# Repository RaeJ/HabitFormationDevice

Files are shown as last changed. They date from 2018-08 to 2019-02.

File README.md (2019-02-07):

# Multisensory Book

This is an IOT device that can be controlled using Alexa. Routines can be set up using the Alexa app so that at the designated
time the book will open up and use a variety of modalities to get the users' attention. The code used to make the sound work is 
from [SFX-I2S-web-trigger](https://github.com/bbx10/SFX-I2S-web-trigger) whilst the code used for being able to connect to
Alexa is from [arduino-esp8266-alexa-wemo-switch](https://github.com/kakopappa/arduino-esp8266-alexa-wemo-switch).

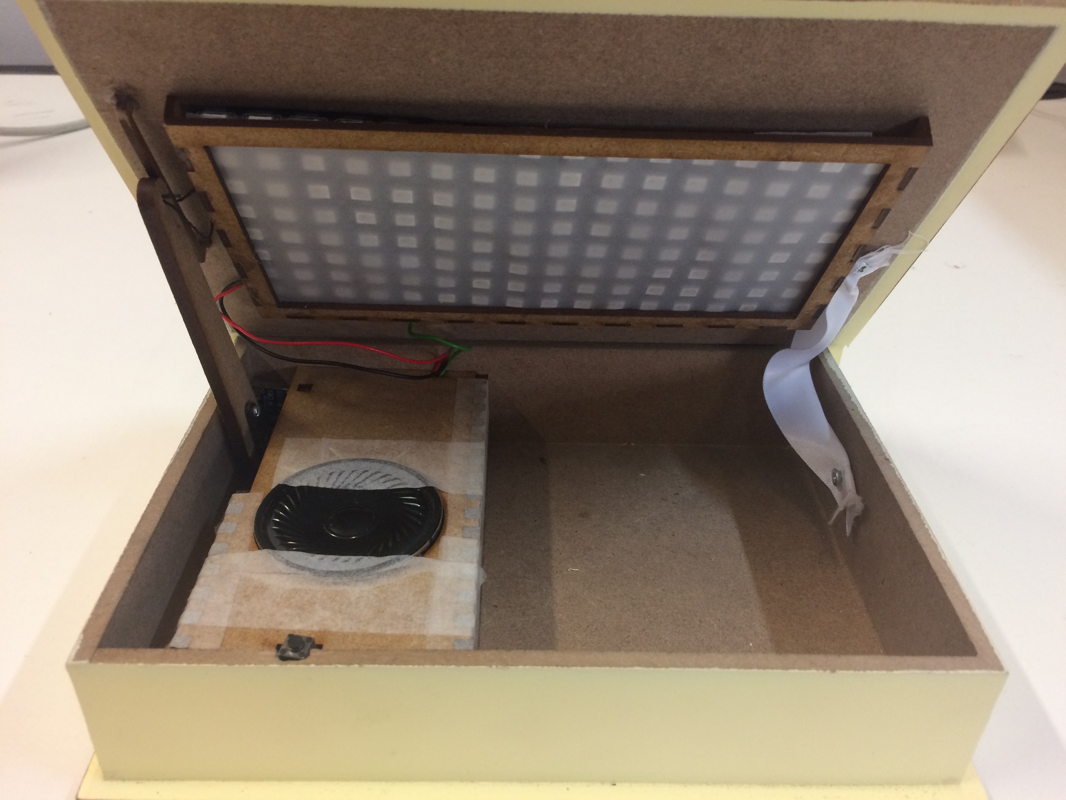
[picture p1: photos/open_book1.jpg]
Multisensory Book


## How to run the device
### Initial Code Setup
1. Download the repository. Some of the files relate to how to make the physical device. The files you need to make sure you have for the code are "book_device.ino", "wavspiffs.cpp", "wavspiffs.h" and "data". "data" contains the .wav file that the device plays and the "wavspiffs" files are from [bbx10](https://github.com/bbx10/SFX-I2S-web-trigger). The main file we are concerned with is "book_device.ino".
2. Change the network name and password. These can be found as follows in the code. If using eduroam take a look at the section of the readme on **Internet Access**.
```
const char* ssid = "NameOfNetwork";  // CHANGE: Wifi name
const char* password = "AardvarkBadgerHedgehog";  // CHANGE: Wifi password 
String friendlyName = "TheDevice";        // CHANGE: Alexa device name
```
You can also change the name of the device should you so wish.

### Initial Arduino Editor Setup
Based off the [Arduino IDE for ESP8266](https://learn.adafruit.com/adafruit-feather-huzzah-esp8266/using-arduino-ide) and the [file system setup](http://esp8266.github.io/Arduino/versions/2.0.0/doc/filesystem.html).

1. Install the the [SiLabs CP2104 Driver](https://www.silabs.com/products/development-tools/software/usb-to-uart-bridge-vcp-drivers). This will allow you to upload code to the ESP8266 using a micro USB cable to the Feather HUZZAH with the other side in your computer's USB port.
2. Install the [Arduino IDE 1.6.8 or greater](https://www.arduino.cc/en/Main/Software) and open it up.
3. Install the ESP8266 Board Package. To do this navigate to *Arduino* *Preferences* and enter `http://arduino.esp8266.com/stable/package_esp8266com_index.json` into the *Additional Board Manager URLs* field. Then navigate to the *Boards Manager* (found under *Tools*->*Board*) and install the ESP8266 Board Package. Close the Boards Manager window once the install process has completed. [This guide](https://learn.adafruit.com/add-boards-arduino-v164) is a good resource to use if you have trouble adding 3rd party boards.
4. Restart the Arduino Editor.
5. Select Adafruit Feather HUZZAH ESP8266  from the *Tools*->*Board* dropdown. Whilst still in *Tools* set the *CPU frequency* as 80MHz. The *Flash Size* can be kept at 4M (3M SPIFFS). For *Upload Speed*, select 115200 baud. You will also need to set the port as whichever port you are using.

From here we want to install the ESP8266FS tool.
1. Download the tool: https://github.com/esp8266/arduino-esp8266fs-plugin/releases/download/0.1.3/ESP8266FS-0.1.3.zip.
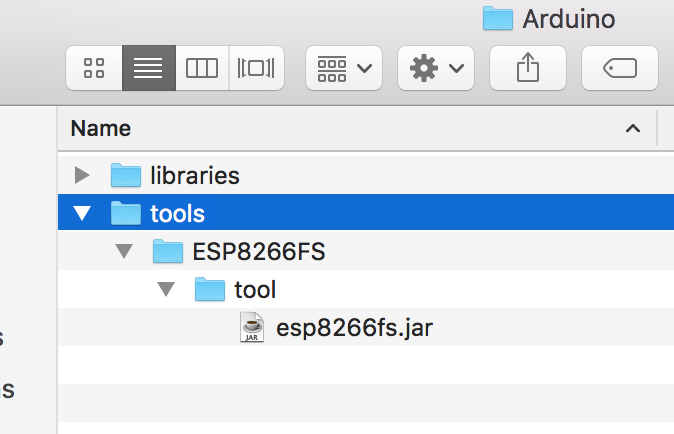
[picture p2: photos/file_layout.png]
File layout
2. In your Arduino sketchbook directory, create tools directory if it doesn't exist yet. Unpack the tool into tools directory, the path should look like `<home_dir>/Arduino/tools/ESP8266FS/tool/esp8266fs.jar`.
3. Restart the Arduino Editor. Under *Tools* there should now be an option for *ESP8266 Sketch Data Upload*.

### Uploading the code to the Feather HUZZAH
1. Connect any data-capable micro USB cable to the Feather HUZZAH and the other side to your computer's USB port. This can be done by carefully pushing the Feather HUZZAH down so it slightly sticks out of the bottom of its encasing box (as shown in the photo). 
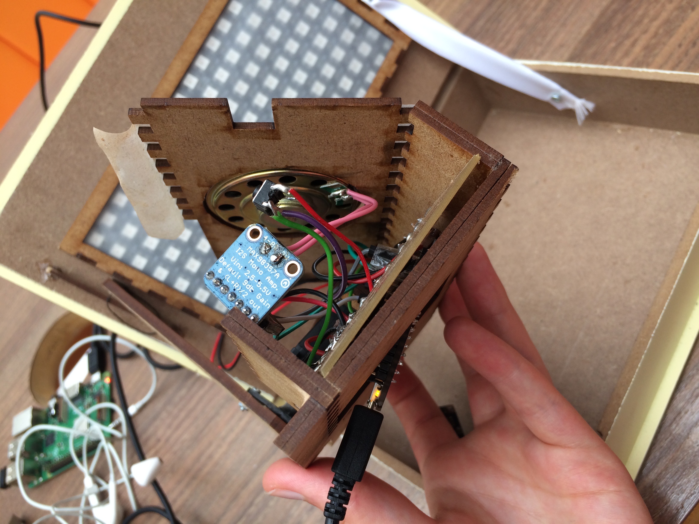
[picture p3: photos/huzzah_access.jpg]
Accessing the Feather HUZZAH


2. Make sure that the Arduino Editor is set to the correct port (*Tools*->*Port*).
3. If you have changed the .wav file in "data", or it is your first time uploading the file to the Feather Huzzah, click on *ESP8266 Sketch Data Upload* in *Tools* and wait for it to upload.
4. When that is finished click the upload button in the Arduino Editor to upload the code to the Feather Huzzah.

### Modality Switching
If you wish to change the intensity of the device this can be done simply by altering this piece of code:
```
// Mode of intensity
char subtle = 'S';
char mediocre = 'M';
char intensive = 'I';

char mode = subtle;
```
Simply change `char mode =` depending on what you want. Then re-upload the code to the Feather HUZZAH

### Controlling the device with Alexa
1. Set up your Alexa device with the Alexa App.
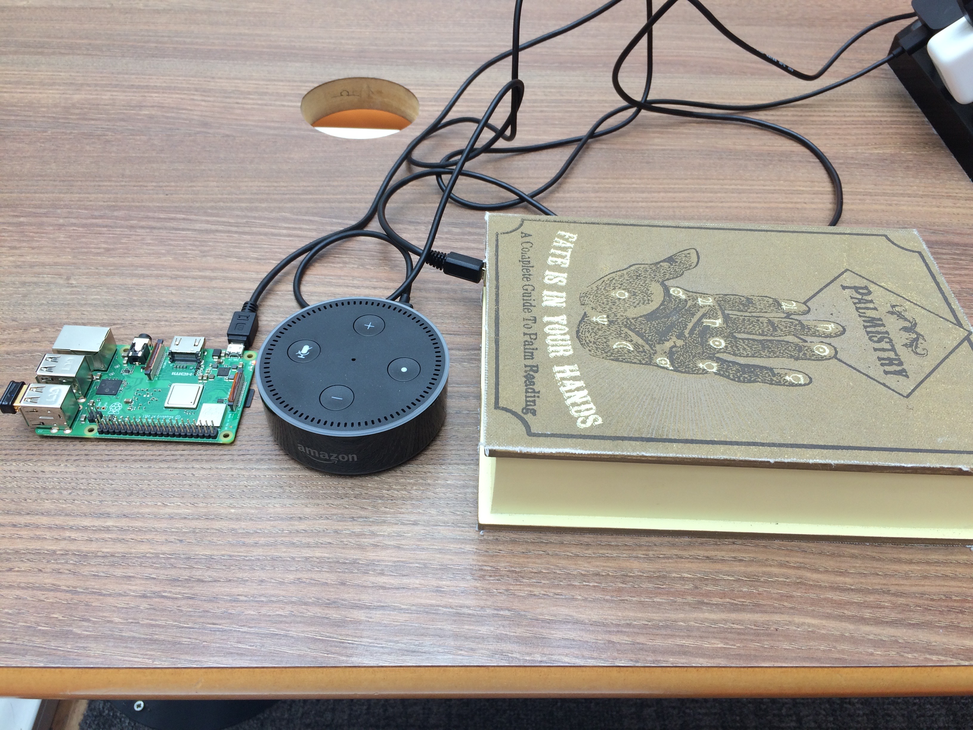
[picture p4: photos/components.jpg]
Components set up
2. Make sure that you are connected to the internet and the device is powered on. 
3. Go into *Settings*->*Smart Home* and click *Add Device*. Alexa should discover the device under the friendly name you've chosen for it.
4. From here you can treat the device as you would any other smart home device, you can create routines for it and turn it on and off with Alexa via voice command.

## Internet Access
The Raspberry Pi is simply used for internet access. In order for the device to be able to work both the ESP8266 and the Alexa need internet access. If you're using a secure network (such as eduroam) it may be difficult to connect up the devices. I'm using a Raspberry Pi 3 B+ and a USB wifi dongle. I connect the wifi dongle up to eduroam by following [these instructions](https://www.willprice.org/2014/03/17/eduroam-on-the-raspberry-pi.html) by the wonderful Will Price, simply replacing wlan0 with wlan1. I then set the wifi chip on the Raspberry Pi board up as a hotspot by following [this guide](https://www.raspberrypi.org/documentation/configuration/wireless/access-point.md). From here you can connect to the hotspot which should then give you access to eduroam and the internet.

When setting up eduroam on the Raspberry Pi I initially made the mistake of running the wpa_supplicant more than once. If you type `pgrep wpa_supplicant` into your terminal there should be only one process running. If there is more then one you can type `pkill wpa_supplicant` to kill them and start over.

Further to this, following Will Price's instructions did give me internet access, however, I initially had to repeat the process every time I restarted the Raspberry Pi. The easy fix for this was to move the terminal commands into the /etc/rc.local file.

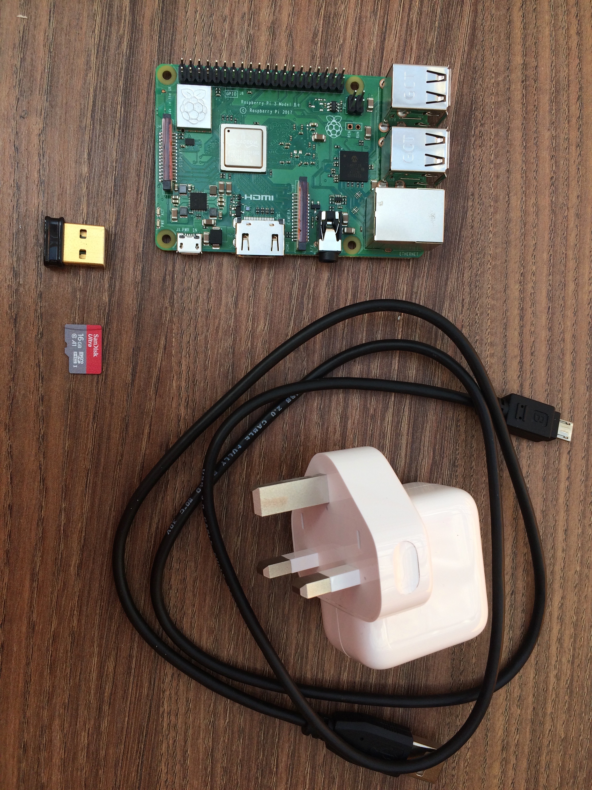
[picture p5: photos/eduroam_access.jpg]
Eduroam access kit


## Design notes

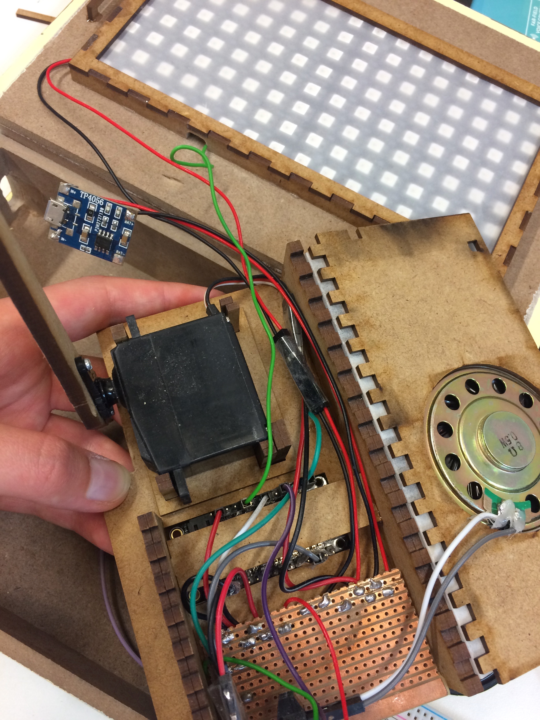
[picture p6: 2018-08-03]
photos/electronics.jpg

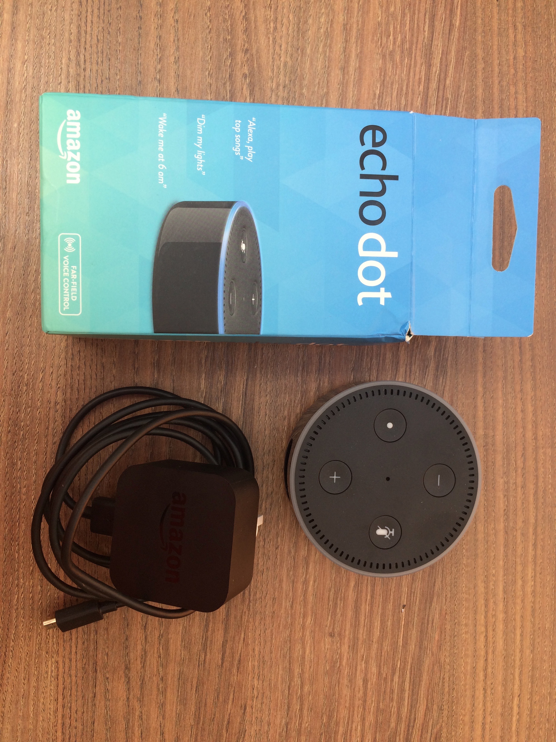
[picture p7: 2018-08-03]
photos/echo_dot.jpg

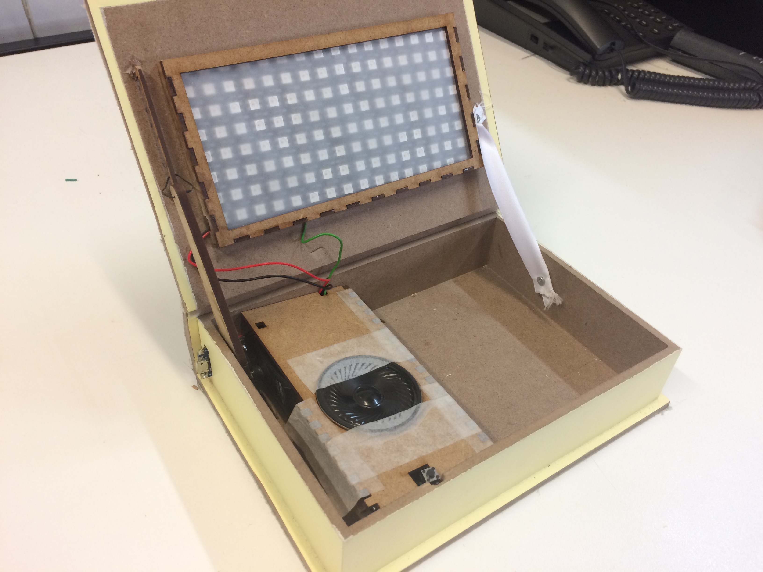
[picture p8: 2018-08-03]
photos/open_book2.jpg

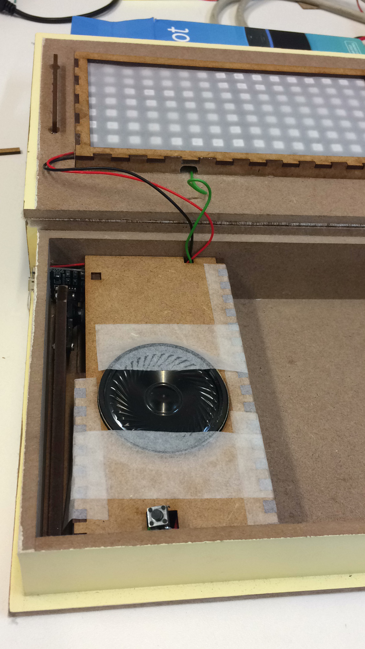
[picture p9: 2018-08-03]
photos/open_book3.jpg

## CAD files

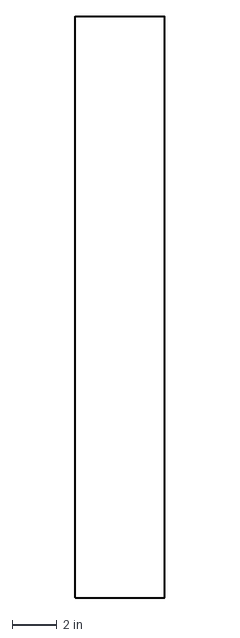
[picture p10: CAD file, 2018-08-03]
construction/support_1.dxf
4.00 x 26.0 in

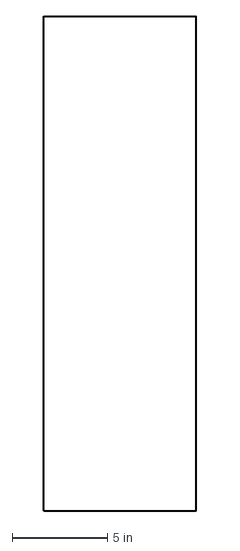
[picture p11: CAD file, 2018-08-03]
construction/support_2.dxf
8.00 x 26.0 in

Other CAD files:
construction/slider.dxf
construction/inner_wall.dxf
construction/LED_frame_front.dxf
construction/LED_frame_base.dxf
construction/LED_frame_right.dxf
construction/base.dxf
construction/divider.dxf
construction/roof.dxf
construction/servo_support.dxf
construction/LED_frame_left.dxf
construction/wall.dxf

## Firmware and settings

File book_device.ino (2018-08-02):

#include <Adafruit_GFX.h>
#include <Adafruit_NeoMatrix.h>
#include <Adafruit_NeoPixel.h>
#include <Servo.h>
#include <ESP8266WiFi.h>
#include <ESP8266WebServer.h>
#include <WiFiUdp.h>
#include <functional>

#include <i2s.h>
#include "wavspiffs.h"

void respondToData();
void prepareIds();
boolean connectWifi();
boolean connectUDP();
void startHttpServer();
void turnOnDevice();
void turnOffDevice();
void sendDeviceState();

const char* ssid = "NameOfNetwork";  // CHANGE: Wifi name
const char* password = "AardvarkBadgerHedgehog";  // CHANGE: Wifi password 
String friendlyName = "TheDevice";        // CHANGE: Alexa device name
#define PIN 14
const int buttonPin = 16;     // the number of the pushbutton pin

Servo hinge;  // create servo object to control a servo

WiFiUDP UDP;
IPAddress ipMulti(239, 255, 255, 250);
ESP8266WebServer HTTP(80);
boolean udpConnected = false;
unsigned int portMulti = 1900;      // local port to listen on
unsigned int localPort = 1900;      // local port to listen on
boolean wifiConnected = false;
char packetBuffer[UDP_TX_PACKET_MAX_SIZE]; //buffer to hold incoming packet,
String serial;
String persistent_uuid;
boolean cannotConnectToWifi = false;

int angle = 0;
bool opened = false;
bool soundPlayed = false;
bool finishedPlaying = false;
int hingeSpeed = 0;
  
Adafruit_NeoMatrix matrix = Adafruit_NeoMatrix(8, 8, 2, 1, PIN,
  NEO_TILE_BOTTOM   + NEO_TILE_LEFT   + NEO_TILE_ROWS   + NEO_TILE_PROGRESSIVE +
  NEO_MATRIX_BOTTOM + NEO_MATRIX_LEFT + NEO_MATRIX_ROWS + NEO_MATRIX_ZIGZAG,
  NEO_GRB + NEO_KHZ800);

//------------------------------------------------------------------------------------------------------------------------//

// Colours defined
const uint16_t none = matrix.Color(0, 0, 0);
const uint16_t red = matrix.Color(255, 0, 0);
const uint16_t green = matrix.Color(0, 255, 0);
const uint16_t blue = matrix.Color(0, 0, 255);
const uint16_t white = matrix.Color(255, 255, 255);
const uint16_t yellow = matrix.Color(255, 255, 0);
const uint16_t purple = matrix.Color(255, 0, 255);
const uint16_t turq = matrix.Color(0, 255, 255);

//------------------------------------------------------------------------------------------------------------------------//

// Mode of intensity
char subtle = 'S';
char mediocre = 'M';
char intensive = 'I';

char mode = subtle;

//------------------------------------------------------------------------------------------------------------------------//

char* activity = "Just do it";

//------------------------------------------------------------------------------------------------------------------------//

void setup() {

  switch( mode ){
    case 'I':
      matrix.setBrightness(75);
      hingeSpeed = 15;
      break;
    case 'M':
      matrix.setBrightness(30);
      hingeSpeed = 40;
      break;
    default: // subtle
      matrix.setBrightness(15);
      hingeSpeed = 75;
  }
  
  hinge.attach(5);  // attaches the servo on pin 12 to the servo object
  hinge.write(angle);
  matrix.begin();
  matrix.setTextWrap(false);
  colorWipe(none, 30);

  pinMode(buttonPin, INPUT);
  Serial.begin(115200); Serial.println();
  Serial.println(F("\nESP8266 Sound Effects Web Trigger"));

  if (!SPIFFS.begin()) {
    Serial.println("SPIFFS.begin() failed");
    return;
  }
  // Confirm track files are present in SPIFFS
  showDir();

  wav_setup();

  prepareIds();
  
  // Initialise wifi connection
  wifiConnected = connectWifi();

  // only proceed if wifi connection successful
  if(wifiConnected){
    Serial.println("Ask Alexa to discover devices");
    udpConnected = connectUDP();
    
    if (udpConnected){
      // initialise pins if needed 
      startHttpServer();
    }
  }
}

void loop() {
  colorWipe(none, 30);
  simple_open_close();

  respondToData();
}

void simple_open_close(){
  if(digitalRead(buttonPin) == HIGH && !opened){
    wait_for_release();
    open_book();
  } else if(digitalRead(buttonPin) == HIGH){
    wait_for_release();
    colorWipe(none, 30);
    close_book();
  }
}

void wait_for_release(){
  while(digitalRead(buttonPin) == HIGH){
      //Do nowt
    }
}

bool respond_to_button(){
  if (digitalRead(buttonPin) == HIGH){
    wait_for_release();
    colorWipe(blue, 10);
    colorWipe(none, 10);
    close_book();
    return true;
  }
  return false;
}

void intense_mode(){
  bool buttonPressed = false;
  intense_movement();
  open_book();
  
  while(opened){
    if(colorWipe(red, 10)){
      break;
    }
    
    while(!finishedPlaying){
      if(!soundPlayed){
        wav_startPlayingFile("/ZapFX001.wav");
        soundPlayed = true;  
      }
      if(wav_loop()){
        buttonPressed = true;
      }
    }
    soundPlayed = false;
    finishedPlaying = false;
    
    if(buttonPressed){
      break;
    }
    if(theaterChase(red, 50, 50)){
      break;
    }
    if(colorWipe(purple, 10)){
      break;
    }
    if(colorWipe(none, 10)){
      break;
    }
    if(display_words(activity, blue, 150)){
      break;
    }
    if(colorWipe(matrix.Color(93, 37, 166), 10)){
      break;
    }
    if(colorWipe(none, 10)){
      break;
    }
    if(theaterChaseRainbow(50)){
      break;
    }
    if(colorWipe(white, 10)){
      break;
    }
    if(theaterChase(white, 50, 50)){
      break;
    }
  }
}

void medi_mode(){
  bool buttonPressed = false;
  some_movement();
  open_book();

  while(!finishedPlaying){
      if(!soundPlayed){
        wav_startPlayingFile("/ZapFX001.wav");
        soundPlayed = true;  
      }
      if(wav_loop()){
        buttonPressed = true;
      }
    }
    soundPlayed = false;
    finishedPlaying = false;

   while(!buttonPressed && opened){
    if(colorWipe(green, 30)){
      break;
    }
    if(theaterChase(green, 90, 30)){
      break;
    }
    if(colorWipe(blue, 30)){
      break;
    }
    if(theaterChase(blue, 70, 40)){
      break;
    }
    if(colorWipe(matrix.Color(111, 0, 255), 30)){
      break;
    }
    if(colorWipe(none, 30)){
      break;
    }
    if(display_words(activity, matrix.Color(111, 0, 255), 150)){
      break;
    }
    if(colorWipe(matrix.Color(146, 146, 30), 30)){
      break;
    }
    if(colorWipe(yellow, 30)){
      break;
    }
    if(colorWipe(matrix.Color(171, 255, 0), 30)){
      break;
    }
  }
}

void subtle_mode(){
  open_book();

  while(opened){
    
    if(colorWipe(turq, 30)){
      break;
    }
    if(colorWipe(blue, 30)){
      break;
    }
    if(colorWipe(matrix.Color(111, 0, 255), 30)){
      break;
    }
    if(colorWipe(matrix.Color(93, 37, 166), 30)){
      break;
    }
    if(colorWipe(matrix.Color(188, 0, 255), 30)){
      break;
    }
    if(colorWipe(purple, 30)){
      break;
    }
    if(colorWipe(matrix.Color(255, 164, 255), 30)){
      break;
    }
    if(colorWipe(white, 30)){
      break;
    }
    
  }
}

void some_movement(){
  for (int pos = 0; pos <= 60 ; pos += 1) {
    hinge.write(pos);
    delay(hingeSpeed); 
  }
  hinge.write(0);
  delay(500);
}

void intense_movement(){
  for(int i=0; i<3; i++){
    hinge.write(30);
    delay(300);
    hinge.write(0);
    delay(300);
  }
  delay(200);
}

void open_book(){
  wait_for_release();
  for (int pos = angle; pos <= 100 ; pos += 1) {
    hinge.write(pos);
    delay(hingeSpeed); 
  }
  angle = 100;
  opened = true;
  onMsg();
  respondToData();
}

void close_book(){
  wait_for_release();
  for (int pos = angle; pos >= 0 ; pos -= 1) {
    hinge.write(pos);
    delay(hingeSpeed);
  }
  angle = 0;
  opened = false;
  offMsg();
  respondToData(); 
  delay(5000);
}

//------------------------------------------------------------------------------------------------------------------------//

// Connection functions

void prepareIds() {
  uint32_t chipId = ESP.getChipId();
  char uuid[64];
  sprintf_P(uuid, PSTR("38323636-4558-4dda-9188-cda0e6%02x%02x%02x"),
        (uint16_t) ((chipId >> 16) & 0xff),
        (uint16_t) ((chipId >>  8) & 0xff),
        (uint16_t)   chipId        & 0xff);

  serial = String(uuid);
  persistent_uuid = "Socket-1_0-" + serial;
}

void respondToSearch() {
    Serial.println("");
    Serial.print("Sending response to ");
    Serial.println(UDP.remoteIP());
    Serial.print("Port : ");
    Serial.println(UDP.remotePort());

    IPAddress localIP = WiFi.localIP();
    char s[16];
    sprintf(s, "%d.%d.%d.%d", localIP[0], localIP[1], localIP[2], localIP[3]);

    String response = 
         "HTTP/1.1 200 OK\r\n"
         "CACHE-CONTROL: max-age=86400\r\n"
         "DATE: Fri, 15 Apr 2016 04:56:29 GMT\r\n"
         "EXT:\r\n"
         "LOCATION: http://" + String(s) + ":80/setup.xml\r\n"
         "OPT: \"http://schemas.upnp.org/upnp/1/0/\"; ns=01\r\n"
         "01-NLS: b9200ebb-736d-4b93-bf03-835149d13983\r\n"
         "SERVER: Unspecified, UPnP/1.0, Unspecified\r\n"
         "ST: urn:Belkin:device:**\r\n"
         "USN: uuid:" + persistent_uuid + "::urn:Belkin:device:**\r\n"
         "X-User-Agent: redsonic\r\n\r\n";

    UDP.beginPacket(UDP.remoteIP(), UDP.remotePort());
    UDP.write(response.c_str());
    UDP.endPacket();                    

     Serial.println("Response sent !");
}

void startHttpServer() {
    HTTP.on("/index.html", HTTP_GET, [](){
      Serial.println("Got Request index.html ...\n");
      HTTP.send(200, "text/plain", "Hello World!");
    });

    HTTP.on("/upnp/control/basicevent1", HTTP_POST, []() {
      Serial.println("########## Responding to  /upnp/control/basicevent1 ... ##########");      

      //for (int x=0; x <= HTTP.args(); x++) {
      //  Serial.println(HTTP.arg(x));
      //}
  
      String request = HTTP.arg(0);      
      Serial.print("request:");
      Serial.println(request);
 
      if(request.indexOf("SetBinaryState") >= 0) {
        if(request.indexOf("<BinaryState>1</BinaryState>") >= 0) {
            Serial.println("Got Turn on request");
//            colorWipe(red, 10);
            turnOnDevice();
        }
  
        if(request.indexOf("<BinaryState>0</BinaryState>") >= 0) {
            Serial.println("Got Turn off request");
            colorWipe(none, 30);
            turnOffDevice();
        }
      }

      if(request.indexOf("GetBinaryState") >= 0) {
        Serial.println("Got binary state request");
        sendDeviceState();
      }
            
      HTTP.send(200, "text/plain", "");
    });

    HTTP.on("/eventservice.xml", HTTP_GET, [](){
      Serial.println(" ########## Responding to eventservice.xml ... ########\n");
      
      String eventservice_xml = "<scpd xmlns=\"urn:Belkin:service-1-0\">"
        "<actionList>"
          "<action>"
            "<name>SetBinaryState</name>"
            "<argumentList>"
              "<argument>"
                "<retval/>"
                "<name>BinaryState</name>"
                "<relatedStateVariable>BinaryState</relatedStateVariable>"
                "<direction>in</direction>"
                "</argument>"
            "</argumentList>"
          "</action>"
          "<action>"
            "<name>GetBinaryState</name>"
            "<argumentList>"
              "<argument>"
                "<retval/>"
                "<name>BinaryState</name>"
                "<relatedStateVariable>BinaryState</relatedStateVariable>"
                "<direction>out</direction>"
                "</argument>"
            "</argumentList>"
          "</action>"
      "</actionList>"
        "<serviceStateTable>"
          "<stateVariable sendEvents=\"yes\">"
            "<name>BinaryState</name>"
            "<dataType>Boolean</dataType>"
            "<defaultValue>0</defaultValue>"
           "</stateVariable>"
           "<stateVariable sendEvents=\"yes\">"
              "<name>level</name>"
              "<dataType>string</dataType>"
              "<defaultValue>0</defaultValue>"
           "</stateVariable>"
        "</serviceStateTable>"
        "</scpd>\r\n"
        "\r\n";
            
      HTTP.send(200, "text/plain", eventservice_xml.c_str());
    });
    
    HTTP.on("/setup.xml", HTTP_GET, [](){
      Serial.println(" ########## Responding to setup.xml ... ########\n");

      IPAddress localIP = WiFi.localIP();
      char s[16];
      sprintf(s, "%d.%d.%d.%d", localIP[0], localIP[1], localIP[2], localIP[3]);
    
      String setup_xml = "<?xml version=\"1.0\"?>"
            "<root>"
             "<device>"
                "<deviceType>urn:Belkin:device:controllee:1</deviceType>"
                "<friendlyName>"+ friendlyName +"</friendlyName>"
                "<manufacturer>Belkin International Inc.</manufacturer>"
                "<modelName>Socket</modelName>"
                "<modelNumber>3.1415</modelNumber>"
                "<modelDescription>Belkin Plugin Socket 1.0</modelDescription>\r\n"
                "<UDN>uuid:"+ persistent_uuid +"</UDN>"
                "<serialNumber>221517K0101769</serialNumber>"
                "<binaryState>0</binaryState>"
                "<serviceList>"
                  "<service>"
                      "<serviceType>urn:Belkin:service:basicevent:1</serviceType>"
                      "<serviceId>urn:Belkin:serviceId:basicevent1</serviceId>"
                      "<controlURL>/upnp/control/basicevent1</controlURL>"
                      "<eventSubURL>/upnp/event/basicevent1</eventSubURL>"
                      "<SCPDURL>/eventservice.xml</SCPDURL>"
                  "</service>"
              "</serviceList>" 
              "</device>"
            "</root>\r\n"
            "\r\n";
            
        HTTP.send(200, "text/xml", setup_xml.c_str());
        
        Serial.print("Sending :");
        Serial.println(setup_xml);
    });

    // openHAB support
    HTTP.on("/on.html", HTTP_GET, [](){
         Serial.println("Got Turn on request");
         HTTP.send(200, "text/plain", "turned on");
//         colorWipe(green, 10);
         turnOnDevice();
       });
 
     HTTP.on("/off.html", HTTP_GET, [](){
        Serial.println("Got Turn off request");
        HTTP.send(200, "text/plain", "turned off");
        colorWipe(none, 30);
        turnOffDevice();
       });
 
      HTTP.on("/status.html", HTTP_GET, [](){
        Serial.println("Got status request");
 
        String staterespone = "0"; 
        if (opened) {
          staterespone = "1"; 
        }
        HTTP.send(200, "text/plain", staterespone);
      
    });
    
    HTTP.begin();  
    Serial.println("HTTP Server started ..");
}
      
// connect to wifi – returns true if successful or false if not
boolean connectWifi(){
  boolean state = true;
  int i = 0;
  
  WiFi.mode(WIFI_STA);
  WiFi.begin(ssid, password);
  Serial.println("");
  Serial.println("Connecting to WiFi");

  // Wait for connection
  Serial.print("Connecting ...");
  while (WiFi.status() != WL_CONNECTED) {
    delay(500);
    Serial.print(".");
    if (i > 10){
      state = false;
      break;
    }
    i++;
  }
  
  if (state){
    Serial.println("");
    Serial.print("Connected to ");
    Serial.println(ssid);
    Serial.print("IP address: ");
    Serial.println(WiFi.localIP());
  }
  else {
    Serial.println("");
    Serial.println("Connection failed.");
  }
  
  return state;
}

boolean connectUDP(){
  boolean state = false;
  
  Serial.println("");
  Serial.println("Connecting to UDP");
  
  if(UDP.beginMulticast(WiFi.localIP(), ipMulti, portMulti)) {
    Serial.println("Connection successful");
    state = true;
  }
  else{
    Serial.println("Connection failed");
  }
  
  return state;
}

void onMsg(){
  String body = 
      "<s:Envelope xmlns:s=\"http://schemas.xmlsoap.org/soap/envelope/\" s:encodingStyle=\"http://schemas.xmlsoap.org/soap/encoding/\"><s:Body>\r\n"
      "<u:SetBinaryStateResponse xmlns:u=\"urn:Belkin:service:basicevent:1\">\r\n"
      "<BinaryState>1</BinaryState>\r\n"
      "</u:SetBinaryStateResponse>\r\n"
      "</s:Body> </s:Envelope>";

  HTTP.send(200, "text/xml", body.c_str());
        
  Serial.print("Sending :");
  Serial.println(body);
}

void turnOnDevice() {
  if(!opened){
    switch( mode ){
      case 'I':
        intense_mode();
        break;
      case 'M':
        medi_mode();
        break;
      default: // subtle
        subtle_mode();
    }
  }
}

void offMsg(){
  String body = 
      "<s:Envelope xmlns:s=\"http://schemas.xmlsoap.org/soap/envelope/\" s:encodingStyle=\"http://schemas.xmlsoap.org/soap/encoding/\"><s:Body>\r\n"
      "<u:SetBinaryStateResponse xmlns:u=\"urn:Belkin:service:basicevent:1\">\r\n"
      "<BinaryState>0</BinaryState>\r\n"
      "</u:SetBinaryStateResponse>\r\n"
      "</s:Body> </s:Envelope>";

  HTTP.send(200, "text/xml", body.c_str());
        
  Serial.print("Sending :");
  Serial.println(body);
}

void turnOffDevice() {
  colorWipe(none, 10);
  close_book();
}

void sendDeviceState() {
  
  String body = 
      "<s:Envelope xmlns:s=\"http://schemas.xmlsoap.org/soap/envelope/\" s:encodingStyle=\"http://schemas.xmlsoap.org/soap/encoding/\"><s:Body>\r\n"
      "<u:GetBinaryStateResponse xmlns:u=\"urn:Belkin:service:basicevent:1\">\r\n"
      "<BinaryState>";
      
  body += (opened ? "1" : "0");
  
  body += "</BinaryState>\r\n"
      "</u:GetBinaryStateResponse>\r\n"
      "</s:Body> </s:Envelope>\r\n";
 
   HTTP.send(200, "text/xml", body.c_str());
}

void respondToData(){
  HTTP.handleClient();
  delay(1);
  
  // if there's data available, read a packet
  // check if the WiFi and UDP connections were successful
  if(wifiConnected){
    if(udpConnected){    
      // if there’s data available, read a packet
      int packetSize = UDP.parsePacket();
      
      if(packetSize) {
        //Serial.println("");
        //Serial.print("Received packet of size ");
        //Serial.println(packetSize);
        //Serial.print("From ");
        IPAddress remote = UDP.remoteIP();
        
        for (int i =0; i < 4; i++) {
          Serial.print(remote[i], DEC);
          if (i < 3) {
            Serial.print(".");
          }
        }
        
        Serial.print(", port ");
        Serial.println(UDP.remotePort());
        
        int len = UDP.read(packetBuffer, 255);
        
        if (len > 0) {
            packetBuffer[len] = 0;
        }

        String request = packetBuffer;
        //Serial.println("Request:");
        //Serial.println(request);
        
        // Issue https://github.com/kakopappa/arduino-esp8266-alexa-wemo-switch/issues/24 fix
        if(request.indexOf("M-SEARCH") >= 0) {
            // Issue https://github.com/kakopappa/arduino-esp8266-alexa-multiple-wemo-switch/issues/22 fix
            //if(request.indexOf("urn:Belkin:device:**") > 0) {
             if((request.indexOf("urn:Belkin:device:**") > 0) || (request.indexOf("ssdp:all") > 0) || (request.indexOf("upnp:rootdevice") > 0)) {
                Serial.println("Responding to search request ...");
                respondToSearch();
             }
        }
      } else{
        simple_open_close();
      }
      
      delay(10);
    }
  } else {
      Serial.println("Cannot connect to Wifi");
  }
}

//------------------------------------------------------------------------------------------------------------------------//

//Neopixel Matrix Functions

// Fill the dots one after the other with a color
bool colorWipe(uint32_t c, uint8_t wait) {
  for(uint16_t i=0; i<matrix.height(); i++) {
    respondToData();
    if(respond_to_button() || !opened){
      return true;
    }
    for(uint16_t j=0; j<matrix.width(); j++) {
        matrix.drawPixel(j, i, c);
        matrix.show();
        delay(wait);
    }
  }
  return false;
}

void rainbow(uint8_t wait) {
  uint16_t i, j, x;

  for(j=0; j<256*5; j++) { // 5 cycles of all colors on wheel
    for(i=0; i< matrix.height(); i++) {
      for(x=0; x < matrix.width(); x++){
        matrix.drawPixel(x, i, Wheel(((i * 256 / matrix.height()) + j) & 255));
      }
    }
    matrix.show();
    delay(wait);
  }
}

bool rainbowPulse(uint8_t wait, int cycles) {
  uint16_t i, j, x;

  for(j=0; j<256*cycles; j++) {
    respondToData();
    if(respond_to_button()){
      return true;
    }
    for(i=0; i< matrix.height(); i++) {
      for(x=0; x < matrix.width(); x++){
        matrix.drawPixel(x, i, Wheel(((i * x * 256 / ( matrix.height() * matrix.width() )) + j) & 255));
      }
    }
    matrix.show();
    delay(wait);
  }
  return false;
}

//Theatre-style crawling lights.
bool theaterChase(uint32_t c, uint8_t wait, int cycles) {
  for (int j=0; j<cycles; j++) {  //do 10 cycles of chasing
    respondToData();
    if(respond_to_button() || !opened){
      return true;
    }
    for (int q=0; q < 3; q++) {
      for (int x=0; x < matrix.height(); x++) {
        for (int i=0; i < matrix.width(); i=i+3) {
          matrix.drawPixel(i+q, x, c);
//          matrix.drawPixel(i+q+(x%3), x, c);
        }
      }
      matrix.show();
     
      delay(wait);

      for (int x=0; x < matrix.height(); x++) {
        for (int i=0; i < matrix.width(); i=i+3) {
          matrix.drawPixel(i+q, x, 0);
//          matrix.drawPixel(i+q+(x%3), x, 0);
        }
      }
    }
  }
  return false;
}

//Theatre-style crawling lights with rainbow effect
bool theaterChaseRainbow(uint8_t wait) {
  for (int j=0; j < 256; j++) {     // cycle all 256 colors in the wheel
    respondToData();
    if(respond_to_button() || !opened){
      return true;
    }
    for (int q=0; q < 3; q++) {
      for (int x=0; x < matrix.width(); x++) {
        for (int i=0; i < matrix.height(); i=i+3) {
          matrix.drawPixel(x, i+q, Wheel( (i+j) % 255));    //turn every third pixel on
        }
      }
        matrix.show();
       
        delay(wait);
        for (int x=0; x < matrix.width(); x++) {
          for (int i=0; i < matrix.height(); i=i+3) {
            matrix.drawPixel(x, i+q, 0);        //turn every third pixel off
          }
        }
    }
  }
  return false;
}
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

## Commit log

2018-07-17 First commit - starting with the LEDs
2018-07-17 LED functions now working in the way I like
2018-07-18 Back to basics somewhat - book opens and closes by a button push
2018-07-18 Current state
2018-07-18 Still very jittery if trying to do a rainbow of any sorts and am not sure why
    [book_device.ino]
2018-07-19 Neopixels working with the servo
2018-07-20 Got it working for subtle - still wrong context
    [book_device.ino]
2018-07-20 Working and can turn off via button but is buggy
    [book_device.ino]
2018-07-27 Currently buggy closing and stopping properly but does respond to echo
    [book_device.ino]
2018-07-27 Have fixed it though is not the prettiest solution
    [book_device.ino]
2018-08-03 Design of inner support for the electronics
    [LED_frame_base.dxf, LED_frame_front.dxf, LED_frame_left.dxf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]
2018-08-03 Video of the device in action
2018-08-22 Basic arduino IDE setup completed
